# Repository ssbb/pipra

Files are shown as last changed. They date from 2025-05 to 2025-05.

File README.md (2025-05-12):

# Pipra

30-key low-profile electro-capacitive wireless split keyboard.

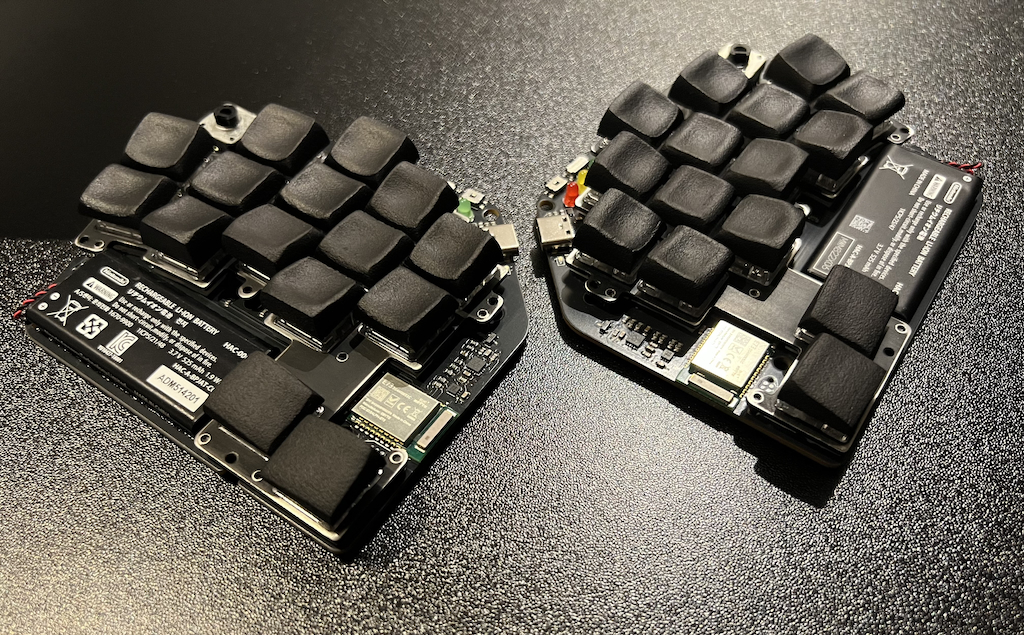
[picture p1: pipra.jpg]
Pipra Keyboard


## Production

The PCB can be assembled via JLCPCB. See production files in the `production` directory.

## Parts

- 6x 3mm LEDs (2x red, 2x yellow, 2x green)
- 2x HAC-006 batteries from Nintendo Joy-Con. Search Amazon or Aliexpress for them.
- 24x M2 screws (5mm or 6mm)

### EC Parts

The only way to get switches currently is to use a Niz L84 or L99 keyboard as a donor.

Search Taobao, e.g., [this](https://detail.tmall.com/item.htm?id=878704443735&skuId=5947860879567) or [this](https://item.taobao.com/item.htm?id=865123524234&skuId=5789959885060).

### Keycaps

This keyboard uses 18x16mm spacing, which means you'll need custom keycaps.

I’m currently aware of a few options:

- [Pseudoku's DC](https://discord.com/channels/714176584269168732/879817722328920174/1351967655707410532) – shared on the Absolem Club Discord server ([invite](https://discord.gg/DbCfZfZ))
- [Fingerpunch CMY](https://github.com/sadekbaroudi/fingerpunch/tree/master/keycaps/CMY)

You can print them on JLCPCB as well.

### Plate

You'll need a 1.5mm metal plate with threaded holes. I used SendCutSend, but you're free to use any laser cutting service. Powder coating is not recommended, as it may alter the cutout dimensions and cause sliders to get stuck in the housings.

Most laser cutting services offer thread tapping, but you can also use a cheap M2 tap yourself.

## Support

[ZMK Firmware](https://github.com/ssbb/pipra-zmk-config)

Feel free to ask any questions in `#ssbb` channel on Absolem Club discord server ([invite](https://discord.gg/DbCfZfZ)).

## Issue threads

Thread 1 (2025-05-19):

what is the purpose of adc_shutdown pin?

kenyujyp, 2025-05-19:
Hello, I am ken, an EC keyboard enthusiast.
Your Pipra EC keyboard is very good design.
But I do not understand the purpose of adc_shutdown pin in your design.
The adc_shutdown pin (P0.06) is designated as power_GPIO in your firmware.
Is this pin used to shutdown ADC chip when keyboard is inactive?
If this is the case, shouldn't this pin connected to VCC pin of ADC chip and VCC pin of multiplexer chip?
Appreciate your help. Thank you.

ssbb, 2025-05-19:
Hi!

Some opamps (eg opa320s, opa357, etc) has shutdown pin which you can use to enable/disable opamp. Firmware using it to disable opamp when not in use (between scans) to reduce power usage. Eg your matrix scan interval set to 5ms - you enable op amp via adc shutdown pin, perform scan, disable op amp, wait 5ms, enable op amp again, perform scan and so on.

Op Amps are quite power hungry so it allows to save quite a lot of power when we don't use them.

kenyujyp, 2025-05-19:
thank you for the answer

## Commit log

2025-05-12 Update production files
    [pipra.kicad_sch, plate.step]
2025-05-12 Do not ignore production bom/positions
    [bom.csv, designators.csv, positions.csv]
2025-05-22 Unify led pins
    [pipra.kicad_sch]
2025-05-26 Remove build artifacts
    [bom.csv, designators.csv, plate.step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]
